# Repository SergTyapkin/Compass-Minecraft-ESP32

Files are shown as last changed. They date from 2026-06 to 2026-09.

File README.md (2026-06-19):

# 🧭 ESP32-C3 Compass & GPS Navigator

**Компас с дизайном из майнкрафта на LED-матрице с магнитометром, GPS-трекером и индикацией заряда аккумулятора**

---

## 📖 Оглавление
1. [Описание проекта](#-описание-проекта)
2. [Функционал](#-функционал)
3. [Управление](#-управление)
4. [Компоненты](#-компоненты)
5. [Схема подключения](#-схема-подключения)
6. [Установка и запуск (PlatformIO)](#-установка-и-запуск-platformio-для-новичков)
7. [Конфигурация](#-конфигурация)
8. [Структура проекта](#-структура-проекта)

---

## 🎯 Описание проекта

Этот проект представляет собой портативный навигационный прибор на базе ESP32-C3 SuperMini с LED-матрицей 8×8. Устройство сочетает в себе:

- **Электронный компас** на основе магнитометра QMC5883L
- **GPS-навигатор** с отображением направления и расстояния до заданной точки
- **Индикатор заряда аккумулятора** с визуальной анимацией на матрице
- **Управление режимами** одной кнопкой

Идеально подходит для геокешинга и подобных квестов или просто как интересный DIY-проект.

---

## ⚡ Функционал

| Режим | Описание |
|---|---|
| **🧭 Компас** | Показывает направление на магнитный север. Стрелка на матрице указывает текущий азимут. Красная стрелка компаса |
| **🎯 GPS-направление** | При наличии GPS-фикса показывает направление (азимут) к сохранённой точке. Зеленая стрелка компаса |
| **📏 GPS-расстояние** | Отображает расстояние до сохранённой точки (в метрах) с цветовой индикацией. Если расстояние > 100 м, количество зеленых кваратиков - количество десятков метров. Если квадратиков матрицы не хватает и метров больше (7x7 * 10), каждый оранжевый квадратик означает 100 м. Если не хватает и оранжевых, то каждый красный означает 1км. |
| **🔋 Индикатор зарядки** | Автоматический режим при подключении зарядки: анимация заполнения батарейки. Зеленая батарейка при полной зарядке. Красная мигающая при проблемах с аккумулятором |

### Дополнительные возможности:
- **Регулировка яркости** LED-матрицы (удержание кнопки)
- **Сохранение GPS-точки** (тройной клик в GPS-режимах)
- **Калибровка компаса** (тройной клик в режиме компаса. Зеленая полоска при калибровке - процент сканирования пространства. Синяя - время калибровки)
- **Автосохранение настроек** в файловой системе LittleFS
- **Визуальная обратная связь** на LED-матрице

---

## 🎮 Управление

Управление осуществляется одной тактильной кнопкой:

| Действие | Результат |
|---|---|
| **Удержание** | Регулировка яркости |
| **1 клик** | Переключение в режиме `GPS`: `GPS-направление` ↔ `GPS-расстояние` |
| **2 клика** | Переключение режима: `Компас` ↔ `GPS` |
| **3 клика** | В режиме `Компас` — **калибровка компаса**<br>В режиме `GPS` — **сохранение текущей позиции** |

> 💡 **Режим зарядки** активируется автоматически при подключении USB-питания. Кнопка в этом режиме неактивна.

---

## 🧩 Компоненты

### 📟 Основные модули

| Компонент | Модель | Ссылка |
|---|---|---|
| Микроконтроллер | ESP32-C3 SuperMini | [Купить на AliExpress](https://ali.click/mwv2d15) |
| GPS-модуль | GY-NEO6MV2 | [Купить на AliExpress](https://ali.click/pvv2d1n) |
| Магнитометр | GY-271 QMC5883L | [Купить на AliExpress](https://ali.click/bvv2d1o) |

### 🔘 Управление и мелочёвка
Нам нужна только одна кнопка и один переключатель
| Компонент | Описание | Ссылка |
|---|---|---|
| Тактильная кнопка | 6×6 мм для управления | [Купить на AliExpress](https://ali.click/jux2d1k) |
| Металлические кнопки | 4×4 мм (для корпуса) | [Купить на AliExpress](https://ali.click/rux2d1s) |
| Переключатели | Мини-переключатели TLZWLA | [Купить на AliExpress](https://ali.click/kyx2d1n) |
| Кулисный переключатель | KCD11-101 | [Купить на AliExpress](https://ali.click/yey2d12) |
| Закладные гайки | M2, M2.5, M3 медные | [Купить на AliExpress](https://ali.click/si03d1q) |

### 💡 Светодиоды

| Компонент | Описание | Ссылка |
|---|---|---|
| LED-матрица | WS2812B 8×8 (Если вы, как и я, не хотите паять матрицу сами. В проекте использована она) | [Купить на AliExpress](https://ali.click/kqo5d1t) |
| WS2812B 2020 | Мини-светодиоды 1.8×2 мм (если хотите паять маленькую матрицу сами) | [Купить на AliExpress](https://ali.click/hzw2d1a) |
| WS2812B 2×2 мм | Компактные RGB-чипы (если хотите паять маленькую матрицу сами) | [Купить на AliExpress](https://ali.click/8ow2d1k) |

### 🔋 Питание

| Компонент | Описание | Ссылка |
|---|---|---|
| Аккумулятор | Любой 3.7V. Я взял 14500, 800 мАч. Можно взять плоский, и сделать корпус тоньше | ссылки нет |
| Плата зарядки | TP4056 Type-C | [Купить на AliExpress](https://ali.click/huv2d18) |

---

## 🔌 Схема подключения

### Основные соединения

| ESP32-C3 | Подключение к |
|---|---|
| **GPIO5** | Кнопка (GND при нажатии) |
| **GPIO0** | LED-матрица (DATA) |
| **GPIO8 (SDA)** | QMC5883L (SDA) |
| **GPIO9 (SCL)** | QMC5883L (SCL) |
| **GPIO20 (RX)** | GPS (TX) |
| **GPIO21 (TX)** | GPS (RX) — опционально |
| **GPIO1** | Датчик заряда (CHG) — LOW при зарядке. Берется с катода красного светодиода индикации зарядки с платы зарядки TP4056. Подключается через подтяжку через резистор 5-10кОм к 3.3V от платы ESP32  |
| **GPIO2** | Датчик заряда (FULL) — LOW при полной зарядке. Берется с катода синего светодиода индикации полного заряда с платы зарядки TP4056. Подключается через подтяжку через резистор 5-10кОм к 3.3V от платы ESP32 |

### Питание

Идеальная схема такая:
```
Внешний блок 5V 2A+
├── 5V  ├──► LED-матрица VCC
|       └──► ESP32-C3 5V
|
└── GND ├──► LED-матрица GND
        └──► ESP32-C3 GND
```

Но у нас:
```
Аккумулятор 3.7V 1A
├── 5V  ├──► LED-матрица VCC
|       └──► ESP32-C3 5V
|
└── GND ├──► LED-матрица GND
        └──► ESP32-C3 GND
```

> ⚠️ **Важно!** LED-матрица требует отдельного питания (не через ESP32). Ведите провод на матрицу сразу от аккумулятора. Общий GND обязателен для всех компонентов.

---

## 🚀 Установка и запуск (PlatformIO для новичков)

### 1. Установка PlatformIO

**Вариант A: Расширение для VS Code (рекомендуется)**

1. Скачайте и установите [Visual Studio Code](https://code.visualstudio.com/)
2. Откройте VS Code, перейдите во вкладку **Extensions** (Ctrl+Shift+X)
3. Найдите **PlatformIO IDE** и установите
4. Перезапустите VS Code

**Вариант B: Альтернативная IDE (CLion, Qt Creator)**

Для других IDE мы подготовили специальный файл `.idea` для быстрого запуска в CLion, а также расширение для Qt Creator. Вы можете использовать любой удобный редактор при наличии установленного PlatformIO Core.

### 2. Клонирование проекта

```bash
git clone https://github.com/SergTyapkin/Compass-Minecraft-ESP32.git
cd Compass-Minecraft-ESP3
```

**Если у вас нет Git:**
- Скачайте ZIP-архив проекта и распакуйте в папку

### 3. Открытие проекта

- В VS Code: **File → Open Folder...** → выберите папку проекта
- PlatformIO автоматически распознает проект

### 4. Подключение платы

1. Подключите ESP32-C3 к компьютеру через USB-C кабель
2. Убедитесь, что в системе появился COM-порт:
   - **Windows:** Диспетчер устройств → Порты (COM и LPT)
   - **Linux:** `ls /dev/ttyUSB*` или `ls /dev/ttyACM*`
   - **macOS:** `ls /dev/cu.usb*`

### 5. Сборка и загрузка прошивки

**Способ 1: Через интерфейс VS Code**
1. Нажмите на иконку PlatformIO в левой панели (в виде пиктограммы с головой робота)
2. В разделе **PROJECT TASKS** выберите:
   - **Build** — сборка проекта
   - **Upload** — загрузка прошивки на плату
   - **Upload and Monitor** — загрузка и открытие монитора порта

**Способ 2: Через терминал**
```bash
pio run --target upload --environment esp32-c3-super-mini
```

### 6. Мониторинг порта

Для просмотра отладочных сообщений:

```bash
pio device monitor --baud 115200
```

Или VS Code кнопка: **Upload and Monitor** сделает это автоматически.

### 7. Первый запуск

После успешной загрузки:
1. На LED-матрице должны загореться тестовые огни
2. В мониторе порта появится сообщение `✅ SETUP COMPLETE!`
3. Начните использовать устройство согласно инструкции управления

---

## ⚙️ Конфигурация

Все настройки проекта находятся в файле [config.h](firmware/src/config.h)

### Индивидуальная настройка

- **Магнитное склонение:** `mag.head.declinDeg = 10` (для вашего региона)
- **Остальные пины и переменные** в config.h

---

## 📁 Структура проекта

```
esp32-compass/
├── src/
│   ├── main.cpp          # Основной код
│   ├── config.h          # Конфигурация пинов
│   ├── icons.h           # Спрайты (иконки на матрице)
│   ├── matrix.h          # Работа с LED-матрицей
│   ├── gfx.h             # Графические примитивы
│   ├── arrows.h          # Данные стрелки компаса
│   ├── arrows.cpp        # Логика стрелки компаса
│   ├── battery.h         # Класс мониторинга заряда
│   └── numbers.h         # Шрифты (цифры 0-9)
├── platformio.ini        # Конфигурация PlatformIO
└── README.md             # Этот файл
```

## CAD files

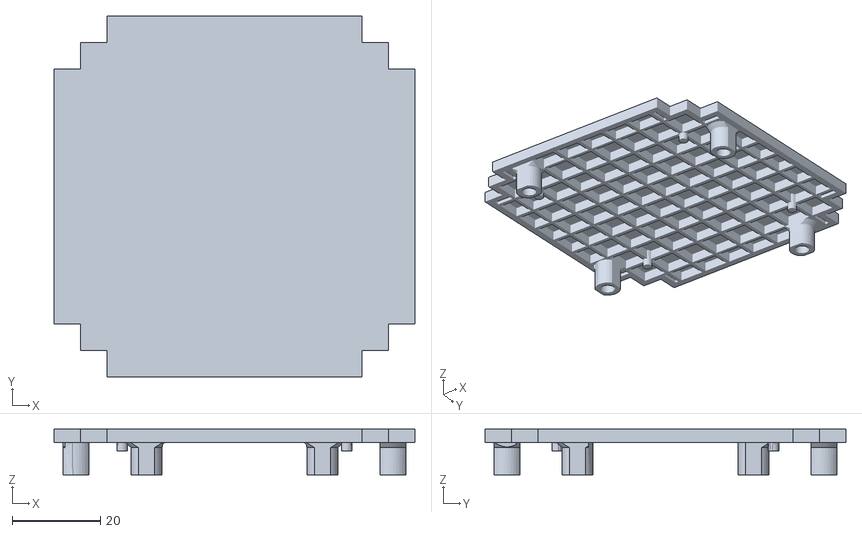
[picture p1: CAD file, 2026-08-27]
3D-модели (STL на печать)/Корпус крышка.stl
82.0 x 82.0 x 10.4

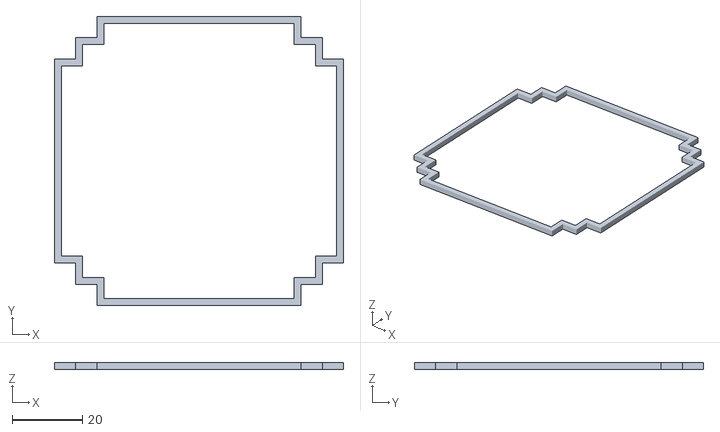
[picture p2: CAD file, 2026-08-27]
3D-модели (STL на печать)/Корпус окантовка.stl
82.0 x 82.0 x 2.00

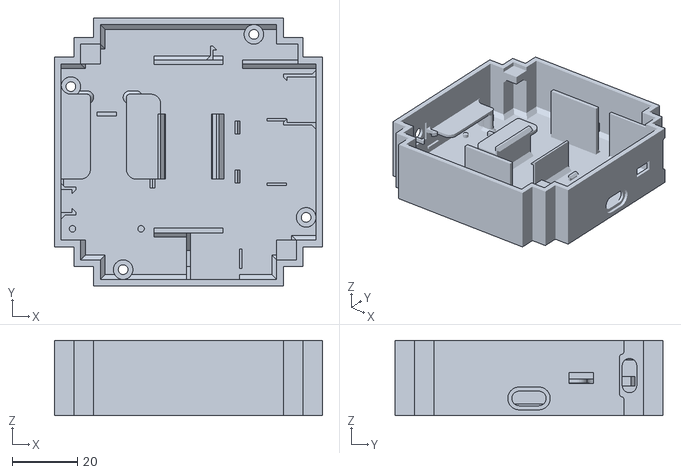
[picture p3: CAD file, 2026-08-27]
3D-модели (STL на печать)/Корпус основа.stl
82.0 x 82.0 x 23.0

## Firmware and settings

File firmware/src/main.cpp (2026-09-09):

#include <Arduino.h>
#include <FileData.h>
#include <GTimer.h>
#include <LittleFS.h>
#include <QMC5883L.h>
#include <TinyGPSPlus.h>
#include <Wire.h>
#include <uButton.h>

#include "config.h"
#include "icons.h"
#include "matrix.h"
#include "battery.h"
#include "timeManager.h"
#include "medianFilter.h"

/*
    Управление кнопкой:

    Удержание:
        В любом режиме - именение яркости. При отпускании и зажатии заново меняет направление изменения яркости (вниз / вверх)
    1x клик:
        🧭 в режиме компаса - ничего
        🌐 в режиме GPS - переключение - показать расстояние до точки / направление к ней
        🕓 в реижме часов - переключение - показать время стрелкой компаса / самими часами
    2x клик - смена режима по кругу:
        => 🧭 Режим компаса -> 🌐 Режим GPS -> 🕓 Режим часов =>
    3x клик:
        🧭 в режиме компаса - калибровка компаса
        🌐 в режиме GPS - запомнить точку
        🕓 в реижме часов - синхрнизация с NPT сервером
*/

enum class Mode {
    Charging,
    Compass,
    TargetDir,
    TargetDist,
    Clock,
    ClockCompass,
};

struct Data {
    uint8_t brightness = 30;
    Mode mode = Mode::Compass;
    MagCal cal;
    float lat;
    float lng;
};
Data cfg;
FileData fdata(&LittleFS, "/cfg.cfg", 'A', &cfg, sizeof(cfg));

uButton btn(BTN_PIN);

QMC5883L mag(I2C_MAG_ADDR);
MedianFilter<int16_t, MAG_FILTER_SIZE> magFilterX;
MedianFilter<int16_t, MAG_FILTER_SIZE> magFilterY;
MedianFilter<int16_t, MAG_FILTER_SIZE> magFilterZ;

TinyGPSPlus gps;

Battery battery(BATTERY_CHARGING_PIN, BATTERY_FULL_PIN);

TimeManager timeManager(WIFI_SSID_NAME, WIFI_PASSWORD, NTP_SERVER_HOST, GMT_OFFSET_SEC, DAYLIGHT_OFFSET_SEC, true);

// Цвета для вывода обычного компаса (красная стрелка)
static uint32_t DefaultCompassArrowColors[] = {
    Adafruit_NeoPixel::Color(255, 0, 0),     // Яркая стрелка
    Adafruit_NeoPixel::Color(60, 0, 0),      // Темная стрелка
    Adafruit_NeoPixel::Color(120, 120, 120), // Центр
};

// Цвета для вывода направления в GPS режиме (зеленая стрелка)
static uint32_t GPSCompassArrowColors[] = {
    Adafruit_NeoPixel::Color(0, 255, 0),     // Яркая стрелка
    Adafruit_NeoPixel::Color(0, 60, 0),      // Темная стрелка
    Adafruit_NeoPixel::Color(120, 120, 120), // Центр
};

// Цвета для вывода часов (красная стрелка)
static uint32_t HourClockCompassArrowColors[] = {
    Adafruit_NeoPixel::Color(255, 0, 0),     // Яркая стрелка
    Adafruit_NeoPixel::Color(60, 0, 0),      // Темная стрелка
    Adafruit_NeoPixel::Color(0, 0, 0), // Центр делаем прозрачным
};
// Цвета для вывода минут (синяя стрелка)
static uint32_t MinuteClockCompassArrowColors[] = {
    Adafruit_NeoPixel::Color(0, 0, 255),     // Яркая стрелка
    Adafruit_NeoPixel::Color(0, 0, 60),      // Темная стрелка
    Adafruit_NeoPixel::Color(0, 0, 0),       // Центр делаем прозрачным
};
// Цвета для вывода дисплея часов
static uint32_t ClockColors[] = {
    Adafruit_NeoPixel::Color(0, 0, 180),     // Светлое небо
    Adafruit_NeoPixel::Color(0, 0, 60),      // Темное небо
    Adafruit_NeoPixel::Color(255, 255, 0),   // Светлая часть стрелки солнца
    Adafruit_NeoPixel::Color(60, 60, 0),     // Темная часть стрелки солнца
    Adafruit_NeoPixel::Color(255, 255, 255), // Светлая часть стрелки луны
    Adafruit_NeoPixel::Color(60, 60, 60),    // Темная часть стрелки луны
};

// ===== BUZZER STATE =====
static bool victoryPointReached = false;
static unsigned long victoryStartTime = 0;
static int victoryNoteIndex = 0;
static bool victoryPlaying = false;

// ===== ANIMATIONS VARS =====
static unsigned long const INITIAL_TIME = millis();

bool onCalibrate(const MagCalProgress& progressMsg) {
    disp.clear();
    disp.color = 0xffff00; // yellow
    disp.drawRectStroke(0, PROGRESS_BAR_Y, PROGRESS_BAR_WIDTH, PROGRESS_BAR_HEGIHT);
    
    // Draw progress
    int progress = progressMsg.balance / CALIBRATION_MIN_PERCENT * (PROGRESS_BAR_WIDTH - 2);
    if (progress > (PROGRESS_BAR_WIDTH - 2)) progress = (PROGRESS_BAR_WIDTH - 2);       // 0.. 8
    disp.color = 0x00ff00; // green
    disp.drawRect(1, PROGRESS_BAR_Y + 1, progress, PROGRESS_BAR_HEGIHT - 3);

    // Draw time
    int elapsedProgress = float(progressMsg.elapsed) / CALIBRATION_MIN_TIME_MS * (PROGRESS_BAR_WIDTH - 2);
    if (elapsedProgress > (PROGRESS_BAR_WIDTH - 2)) elapsedProgress = (PROGRESS_BAR_WIDTH - 2);
    disp.color = 0x0000ff; // blue
    disp.drawRect(1, PROGRESS_BAR_Y + PROGRESS_BAR_HEGIHT - 2, elapsedProgress, 1);

    disp.update();

    return progressMsg.elapsed > CALIBRATION_MIN_TIME_MS && progressMsg.balance > CALIBRATION_MIN_PERCENT;
}

// ===== VICTORY MELODY =====
// Простая восходящая победная мелодия
void playVictoryMelody() {
    // Ноты: C5, D5, E5, G5, C6 (восходящая гамма)
    const int notes[] = {523, 587, 659, 784, 1047};
    const int noteCount = 5;
    
    for (int i = 0; i < noteCount; i++) {
        ledcSetup(BUZZER_PWM_CHANNEL, notes[i], BUZZER_PWM_RESOLUTION);
        ledcWrite(BUZZER_PWM_CHANNEL, 128);  // 50% duty cycle
        delay(BUZZER_TONE_DURATION);
        ledcWrite(BUZZER_PWM_CHANNEL, 0);
        delay(50);  // small pause between notes
    }
}

// ===== NON-BLOCKING VICTORY MELODY =====
void startVictoryMelody() {
    Serial.println("  🔊 Start playing winning melody!");
    victoryPlaying = true;
    victoryNoteIndex = 0;
    victoryStartTime = millis();
    victoryPointReached = true;  // чтобы не повторять
}

void tickBuzzer() {
    if (!victoryPlaying) return;
    
    // Ноты: C5, D5, E5, G5, C6
    const int notes[] = {523, 587, 659, 784, 1047};
    const int noteCount = 5;
    const int noteDuration = 150;
    const int pauseDuration = 50;
    
    static unsigned long lastNoteTime = 0;
    static bool playingNote = true;
    
    if (victoryNoteIndex >= noteCount) {
        // Мелодия завершена
        ledcWrite(BUZZER_PWM_CHANNEL, 0);
        victoryPlaying = false;
        Serial.println("  🔈 Winnng melody played to the end");
        return;
    }
    
    unsigned long now = millis();
    
    if (playingNote) {
        // Включаем ноту
        if (now - lastNoteTime >= noteDuration) {
            ledcWrite(BUZZER_PWM_CHANNEL, 0);
            playingNote = false;
            lastNoteTime = now;
        }
    } else {
        // Пауза между нотами
        if (now - lastNoteTime >= pauseDuration) {
            victoryNoteIndex++;
            if (victoryNoteIndex < noteCount) {
                ledcSetup(BUZZER_PWM_CHANNEL, notes[victoryNoteIndex], BUZZER_PWM_RESOLUTION);
                ledcWrite(BUZZER_PWM_CHANNEL, 128);
                playingNote = true;
                lastNoteTime = now;
            } else {
                // Мелодия завершена
                victoryPlaying = false;
            }
        }
    }
}

void setup() {
    Serial.begin(115200);
    Serial.println("\n╔═══════════════════════════════════╗");
    Serial.println("║     ESP32-C3 GPS Compass          ║");
    Serial.println("╚═══════════════════════════════════╝\n");
    
    Serial.println("STEP 0: Initializing Battery Monitor...");
    battery.init();
    Serial.println("  ✅ Battery monitor initialized");

    Serial.println("STEP 1: Initializing GPS...");
    Serial0.begin(9600, SERIAL_8N1, GPS_UART_PIN_RX, GPS_UART_PIN_TX);  // RX, TX
    Serial.printf("  ✅ GPS UART initialized on pins %d(RX), %d(TX)\n", GPS_UART_PIN_RX, GPS_UART_PIN_TX);

    Serial.println("STEP 2: Initializing File System...");
    LittleFS.begin(true);
    fdata.read();
    Serial.println("  ✅ LittleFS mounted");
    Serial.printf("  ✅ Config loaded: brightness=%d, mode=%d\n", cfg.brightness, (int)cfg.mode);

    Serial.println("STEP 3: Initializing LED Matrix...");
    strip.begin();
    strip.setBrightness(cfg.brightness);
    strip.clear();
    strip.show();
    Serial.println("  ✅ NeoPixel initialized");

    Serial.println("STEP 4: Initializing Magnetometer...");
    Wire.begin(I2C_SDA_PIN, I2C_SCL_PIN);
    Wire.setClock(100000);
    Serial.printf("  ✅ I2C initialized on pins %d(SDA), %d(SCL)\n", I2C_SDA_PIN, I2C_SCL_PIN);

    // Проверяем наличие датчика
    Serial.printf("  🔍 Scanning for magnetometer at 0x%x... ", I2C_MAG_ADDR);
    Wire.beginTransmission(I2C_MAG_ADDR);
    byte error = Wire.endTransmission();
    if (error == 0) {
        Serial.println("✅ FOUND!");
    } else {
        Serial.printf("❌ NOT FOUND! Error: %d\n", error);
        Serial.printf("  Check wiring: SDA=GPIO%d, SCL=GPIO%d, VCC=3.3V, GND=GND\n", I2C_SDA_PIN, I2C_SCL_PIN);
    }
    
    // Принудительная инициализация магнитометра
    Serial.print("  ⚙️  Configuring magnetometer registers... ");
    // 1. Сброс датчика (запись 0x01 в регистр 0x0B)
    Wire.beginTransmission(I2C_MAG_ADDR);
    Wire.write(0x0B);  // Register RESET
    Wire.write(0x01);  // Soft reset
    Wire.endTransmission();
    delay(10);
    // 2. Настройка Control Register (0x09)
    // Биты: [7:6] OSR (00=512 samples)
    //       [5:4] RNG (01=8G)
    //       [3:2] ODR (11=200Hz)
    //       [1:0] MODE (01=continuous mode)
    Wire.beginTransmission(I2C_MAG_ADDR);
    Wire.write(0x09);  // Control register
    Wire.write(0x1D);  // 0b00011101 = continuous mode, 200Hz, 8G, 512 samples
    Wire.endTransmission();
    delay(10);
    // 3. Настройка Set/Reset Period (0x0A)
    Wire.beginTransmission(I2C_MAG_ADDR);
    Wire.write(0x0A);  // Control2 register
    Wire.write(0x01);  // Enable set/reset
    Wire.endTransmission();
    delay(10);
    byte writeError = Wire.endTransmission();
    if (writeError == 0) {
        Serial.println("✅ Control register set to 0x1D");
    } else {
        Serial.printf("❌ Write failed! Error: %d\n", writeError);
    }
    delay(100);
    
    mag.begin();
    mag.cal = cfg.cal;
    Serial.println("  ✅ Magnetometer initialized");

    // ось y вперёд
    mag.head.axis[0] = 0;
    mag.head.axis[1] = 1;
    mag.head.sign[0] = 1;
    mag.head.sign[1] = 1;
    mag.head.declinDeg = 10;
    Serial.println("  ✅ Magnetometer axes configured");

    // сброс фильтров
    magFilterX.reset();
    magFilterY.reset();
    magFilterZ.reset();
    Serial.printf("  ✅ Median filters initialized (size: %d)\n", MAG_FILTER_SIZE);

    // ===== BUZZER INIT =====
    Serial.println("STEP 5: Initializing Buzzer...");
    ledcSetup(BUZZER_PWM_CHANNEL, 440, BUZZER_PWM_RESOLUTION);
    ledcAttachPin(BUZZER_PIN, BUZZER_PWM_CHANNEL);
    ledcWrite(BUZZER_PWM_CHANNEL, 0);
    Serial.printf("  ✅ Buzzer initialized on pin %d\n", BUZZER_PIN);

    // ===== TimeManager INIT =====
    Serial.println("STEP 6: Initializing TimeManager...");
    timeManager.begin();
    Serial.println("  ✅ TimeManager initialized succcessfully");

    // ----- Завершение инициализации
    Serial.println("\n═══════════════════════════════════════");
    Serial.println("✅ SETUP COMPLETED!");
    Serial.println("═══════════════════════════════════════\n");
    
    Serial.println("Controls:");
    Serial.println("  🔄 1 click:");
    Serial.println("    🧭 Compass - nothing");
    Serial.println("    🌐 GPS -     switch target/dist mode");
    Serial.println("    🕓 Clock -   switch compass/clock visual mode");
    Serial.println("  🔄 2 clicks:");
    Serial.println("     Switch mode > 🧭 Compass -> 🌐 GPS -> 🕓 Clock >");
    Serial.println("  🔄 3 clicks:");
    Serial.println("    🧭 Calibrate compass");
    Serial.println("    🌐 Save GPS point");
    Serial.println("    🕓 Sync clock using WiFi");
    Serial.println("  🔄 Hold - adjust brightness\n");
}

void loop() {
    btn.tick();
    fdata.tick();
    tickBuzzer();

    if (Serial0.available()) {
        gps.encode(Serial0.read());
    }

    // ------ Display
    EVERY16_MS(30) { // 30 ms for 30+ fps
        disp.clear();

        Serial.println("\n💠 System monitor info:");
        Serial.printf("  🔆 Brightness: %d / 255\n", cfg.brightness);
        // Проверка подключения зарядки
        Battery::State batteryState = battery.getState();
        Serial.printf(
            "  🔋 Battery state: %s\n", 
            batteryState == Battery::State::STATE_CHARGING ? "🟡 Charging" :
            batteryState == Battery::State::STATE_FULL ? "🟢 Full" :
            batteryState == Battery::State::STATE_ERROR ? "🔴 Error" :
            batteryState == Battery::State::STATE_NOT_CHARGING ? "🔻 OK" :
            "❓ Unknown"
        );

        // Проверка пинов на всякий случай
        const bool batteryIsChargerConnected = battery.isChargerConnected();
        bool chargingPinValue = digitalRead(BATTERY_CHARGING_PIN) == LOW;
        bool fullPinValue = digitalRead(BATTERY_FULL_PIN) == LOW;
        Serial.printf("  🔋 Battery charger connected: %s\n", batteryIsChargerConnected ? "🟢" : "🔸");
        Serial.printf("  🔋 Charging pin:              %s\n", chargingPinValue ? "🟢" : "🔸");
        Serial.printf("  🔋 Full pin:                  %s\n", fullPinValue ? "🟢" : "🔸");
        if (batteryIsChargerConnected) { // Если зарядка подключена - переключаем в режим зарядки
            cfg.mode = Mode::Charging;
            fdata.update();
        } else { // Если нет - возвращаем в обычный, но только если была зарядка
            if (cfg.mode == Mode::Charging) {
                cfg.mode = Mode::Compass;
                fdata.update();
            }
        }

        switch (cfg.mode) {
            case Mode::Charging: {
                Serial.println("💠 Mode: 🔋 Charging");
                switch (battery.getState()) { // Проверяем состояние батарейки
                    case Battery::STATE_FULL: {
                        // ===== РИСУЕМ БАТАРЕЙКУ С ПЛАВНЫМ ПЕРЕЛИВОМ =====
                        unsigned long timeFromStart = millis() - INITIAL_TIME;
                        
                        // Получаем оттенок цвета
                        uint16_t hue = 
                            ANIMATION_BATTERY_FULL_HUE_INITIAL_DEG * 256 +
                            sin(timeFromStart * ANIMATION_BATTERY_FULL_HUE_ANIMATION_SPEED) *
                            ANIMATION_BATTERY_FULL_HUE_AMPLITUDE_DEG * 256;
                        uint32_t frameColor = strip.ColorHSV(hue, 255, ANIMATION_BATTERY_FULL_HUE_BRIGHTNESS);
                        
                        // Рисуем батарейку с плавно меняющимся цветом
                        disp.color = frameColor;
                        disp.drawSprite(battery_full, sizeof(battery_full), 0, 1);
                        Serial.println(" 🔋 Battery FULL");
                        break;
                    }
                    
                    case Battery::STATE_CHARGING: {
                        // ===== 1. РИСУЕМ КОРПУС БАТАРЕЙКИ С ПЛАВНЫМ ПЕРЕЛИВОМ =====
                        unsigned long timeFromStart = millis() - INITIAL_TIME;
                        
                        // Получаем оттенок цвета
                        uint16_t hue = 
                            ANIMATION_BATTERY_HUE_INITIAL_DEG * 256 +
                            sin(timeFromStart * ANIMATION_BATTERY_HUE_ANIMATION_SPEED) *
                            ANIMATION_BATTERY_HUE_AMPLITUDE_DEG * 256;
                        uint32_t frameColor = strip.ColorHSV(hue, 255, ANIMATION_BATTERY_HUE_BRIGHTNESS);
                        
                        // Рисуем корпус батарейки с плавно меняющимся цветом
                        disp.color = frameColor;
                        disp.drawSprite(battery_frame, sizeof(battery_frame), 0, 1);
                        
                        // ===== 2. АНИМАЦИЯ ЗАПОЛНЕНИЯ ПОЛОСЫ ЗАРЯДКИ ГРАДИЕНТНОЙ ВОЛНОЙ =====
                        static unsigned long lastAnimUpdate = 0;
                        static int wavePosition = -ANIMATION_WAVE_WIDTH;
                        
                        // Обновляем анимацию (волна шагает)
                        if (millis() - lastAnimUpdate > ANIMATION_WAVE_STEP_MS) {
                            lastAnimUpdate = millis();
                            
                            // Фаза волны
                            wavePosition++;
                            if (wavePosition > ANIMATION_WAVE_MAX_POSITION) {
                                wavePosition = -ANIMATION_WAVE_WIDTH;
                            }
                        }
                        
                        // Определяем яркость каждого пикселя в зависимости от позиции волны
                        // Используем 5x2 область полосы для заполнения (x = 1..5, y = 2..3)
                        for (int y = 2; y <= 3; y++) {
                            for (int x = 1; x <= 5; x++) {
                                // Вычисляем расстояние от текущей позиции до центра волны
                                int distFromWave = abs(x - wavePosition);
                                
                                // Яркость зависит от расстояния до центра волны:
                                uint8_t brightness = 0;
                                // Ремаппинг расстояния в яркость (0-max) -> (255-0)
                                brightness = map(distFromWave, 0, ANIMATION_WAVE_WIDTH + 0.01, ANIMATION_WAVE_MAX_BRIGHTNESS, 0);
                                
                                if (distFromWave > ANIMATION_WAVE_WIDTH) {
                                    continue;
                                }

                                uint32_t waveColor = strip.ColorHSV(ANIMATION_WAVE_HUE_DEG * 256, 255, brightness);
                                disp.color = waveColor;
                                disp.drawPixel(x, y);
                            }
                        }
                        break;
                        Serial.println(" 🔋 Battery in charging... Playing wave animation");
                    }
                    
                    case Battery::STATE_ERROR: {
                        // Ошибка - быстро моргаем красной батарейкой
                        static bool blinkState = false;
                        static unsigned long lastBlink = 0;
                        
                        if (millis() - lastBlink > 200) {
                            lastBlink = millis();
                            blinkState = !blinkState;
                        }
                        
                        if (blinkState) {
                            disp.color = 0xff0000;
                            disp.drawSprite(battery_frame, sizeof(battery_frame), 0, 1);
                            Serial.println(" 🔋❌ BATTERY ERROR!");
                        } else {
                            disp.clear();
                        }
                        break;
                    }
                    
                    case Battery::STATE_NOT_CHARGING: // Вообще мы не долдны сюда попадать, но на всякий случай
                    default: {
                        // Не заряжается - тусклая рамка батарейки
                        disp.color = 0x444444;
                        disp.drawSprite(battery_frame, sizeof(battery_frame), 0, 1);
                        Serial.println(" 🔋 Not charging");
                        break;
                    }
                }
                break;
            }

            case Mode::Compass: {
                // ===== ЧТЕНИЕ С ФИЛЬТРАЦИЕЙ =====
                MagRaw rawValues = mag.readRaw();
                
                // Добавляем в фильтры
                magFilterX.add(rawValues.x);
                magFilterY.add(rawValues.y);
                magFilterZ.add(rawValues.z);
                
                // Получаем отфильтрованные значения
                int16_t filteredX, filteredY, filteredZ;
                if (magFilterX.isFull()) {
                    filteredX = magFilterX.getMedian();
                    filteredY = magFilterY.getMedian();
                    filteredZ = magFilterZ.getMedian();
                } else {
                    // Пока фильтр не заполнен, используем сырые данные
                    filteredX = rawValues.x;
                    filteredY = rawValues.y;
                    filteredZ = rawValues.z;
                }
                
                // Вычисляем heading из отфильтрованных данных
                float heading = atan2(filteredY, filteredX);
                if (heading < 0) heading += TWO_PI;
                
                Serial.println("💠 Mode: 🧭 Compass");
                Serial.printf("  🧭 RAW values: X=%6d Y=%6d Z=%6d\n", rawValues.x, rawValues.y, rawValues.z);
                Serial.printf("  🧭 FILT values: X=%6d Y=%6d Z=%6d\n", filteredX, filteredY, filteredZ);
                Serial.printf("  🧭 Heading=%.2f rad (%.1f°)\n", heading, degrees(heading));
                
                // Выводим стрелку компаса
                showArrowRad(COMPASS_ROTATION_OFFSET_RAD - heading, DefaultCompassArrowColors);
                break;
            }

            case Mode::TargetDir:
                Serial.println("💠 Mode: 🌐 GPS target to DIR");

                if (gps.location.isValid()) {
                    Serial.printf("  🌐 GPS: Lat=%.6f Lon=%.6f Sats=%d\n", gps.location.lat(), gps.location.lng(), gps.satellites.value());
                    float headDeg = gps.courseTo(gps.location.lat(), gps.location.lng(), cfg.lat, cfg.lng);
                    float heading = mag.headingRad();
                    Serial.printf("  🌐 TargetDir: headDeg=%.2f, heading=%.2f\n", headDeg, heading);
                    showArrowRad(radians(headDeg) - heading, GPSCompassArrowColors);
                    float hdop = gps.hdop.hdop();
                    disp.color = Adafruit_NeoPixel::ColorHSV(hdop ? map(hdop, 20, 0, 0, 20000) : 0);
                    disp.drawPixel(5, 2);  // center
                } else {
                    Serial.printf("  🌐 GPS: ❌ No fix (satellites=%d)\n", gps.satellites.value());
                    disp.color = 0xff0000;
                    disp.drawSprite(cross, sizeof(cross));
                }
                break;

            case Mode::TargetDist:
                Serial.println("💠 Mode: 🌐 GPS DIST to target");
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

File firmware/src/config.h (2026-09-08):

#pragma once

// Button
#define BTN_PIN 5                         // Пин кнопки

// LED matrix
#define LED_PIN 0                        // Пин для сигнала в LED-матрицу
#define LED_COUNT 64                     // Количество светодиодов (8×8)
#define LED_MATRIX_WIDTH 8               // Ширина матрицы (отдельно, потому что она может быть сложной формы. Это размеры описанного прямоугольника вокруг неё)
#define LED_MATRIX_HEIGHT 8              // Высота матрицы

// Pins I2C (Magnitometer)
#define I2C_SDA_PIN 8                    // SDA для магнитометра
#define I2C_SCL_PIN 9                    // SCL для магнитометра
#define I2C_MAG_ADDR 0x2C                // I2C адрес QMC5883L (обычно 0x0D)

// GPS pins and distance
#define GPS_UART_PIN_RX 20               // RX ESP32 (подключается к TX GPS)
#define GPS_UART_PIN_TX 21               // TX ESP32 (подключается к RX GPS)
#define GPS_DISTANCE_TO_POINT_REACHED_METERS 3 // Расстояние до точки, чтобы она считалась достигнутой

// Buzzer
#define BUZZER_PIN 4                     // Пин пьезоэлемента (пищалки)
#define BUZZER_PWM_CHANNEL 1             // Ну надо так
#define BUZZER_PWM_RESOLUTION 8          // Ну надо так
#define BUZZER_TONE_DURATION 150         // ms на одну ноту музыки

// Pins Battery Monitor (TP4056 plate)
#define BATTERY_CHARGING_PIN 2           // Пин индикации зарядки с TP4056 (LOW = заряжается)
#define BATTERY_FULL_PIN 1               // Пин индикации заряда с TP4056 (LOW = заряжена)

// Calibration parameters
#define CALIBRATION_MIN_TIME_MS 10000
#define CALIBRATION_MIN_PERCENT 0.75

// Filtering
#define MAG_FILTER_SIZE 15               // Размер медианного фильтра для магнитометра

// Time manager settings
#define WIFI_SSID_NAME "Sergs-Archer-E204"    // Название сети Wifi
#define WIFI_PASSWORD "<YOUR_WIFI_PASSWORD>"  // Пароль от Wifi
#define NTP_SERVER_HOST "pool.ntp.org"   // Хост NTP сервера для синхронизации времени
#define GMT_OFFSET_SEC (3 * 60 * 60)     // Смещение часового пояса GMT+3
#define DAYLIGHT_OFFSET_SEC 0            // Смещение летнего/зимнего времени

// Controls
#define BRIGHTNESS_STEP 5                // Шаг яркости при зажатии кнопки
#define BRIGHTNESS_MIN  1                // Минимальное значение яркости
#define BRIGHTNESS_MAX  255              // Максимальное значение яркости

// Visuals
#define COMPASS_ROTATION_OFFSET_RAD (PI)    // Смещение при выводе фреймов компаса (чтобы направление севера магнитометра совпадало со стрелкой)
// 🔁 Calibration progressbar params
#define PROGRESS_BAR_HEGIHT 4                                         // Ширина прогрессбара (по вертикали. Не меньше 4)
#define PROGRESS_BAR_WIDTH LED_MATRIX_WIDTH                           // Длина прогрессбара (по вертикали. Не меньше 5)
#define PROGRESS_BAR_Y ((LED_MATRIX_HEIGHT - PROGRESS_BAR_HEGIHT) / 2)  // Y позиция, откуда рисуем прогрессбар
// 🔋🟡 Charging animantion params
// | Corpus
#define ANIMATION_BATTERY_HUE_INITIAL_DEG 32                 // Средний оттенок в HSV для заряжающейся батарейки (30 - желтый)
#define ANIMATION_BATTERY_HUE_AMPLITUDE_DEG 10               // Амплитуда анимации оттенка для заряжающейся батарейки
#define ANIMATION_BATTERY_HUE_ANIMATION_SPEED 0.001          // Скорость изменения оттенка для заряжающейся батарейки
#define ANIMATION_BATTERY_HUE_BRIGHTNESS cfg.brightness      // Яркость анимации заряжающейся батарейки
// | Filling
#define ANIMATION_WAVE_WIDTH 5                               // Длина изредка пробегающей волны зарядки
#define ANIMATION_WAVE_MAX_POSITION 15                       // Дальнее положение пробегающей волны зарядки
#define ANIMATION_WAVE_STEP_MS 30                            // Скорость пробегания волны
#define ANIMATION_WAVE_MAX_BRIGHTNESS cfg.brightness         // Яркость волны
#define ANIMATION_WAVE_HUE_DEG 50                            // Оттенок в HSV для волны (50 - между желтым и зеленым)
// 🔋🟢 Charged animantion params
#define ANIMATION_BATTERY_FULL_HUE_INITIAL_DEG 90            // Средний оттенок в HSV для заряженной батарейки (90 - зеленый)
#define ANIMATION_BATTERY_FULL_HUE_AMPLITUDE_DEG 15          // Амплитуда анимации оттенка для заряженной батарейки
#define ANIMATION_BATTERY_FULL_HUE_ANIMATION_SPEED 0.001     // Скорость изменения оттенка для заряженной батарейки
#define ANIMATION_BATTERY_FULL_HUE_BRIGHTNESS cfg.brightness // Яркость анимации заряженной батарейки
// 🕓 Clock
#define CLOCK_MATRIX_X 0       // Начало отрисовки часов на матрице по X
#define CLOCK_MATRIX_Y 0       // Начало отрисовки часов на матрице по Y
#define CLOCK_MATRIX_WIDTH 7   // Ширина области матрицы для часов. Лучше нечетные числа
#define CLOCK_MATRIX_HEIGHT 7  // Высота области матрицы для часов. Лучше нечетные числа
// 🌐 GPS
#define GPS_MATRIX_X 0       // Начало отрисовки gps компаса на матрице по X
#define GPS_MATRIX_Y 0       // Начало отрисовки gps компаса на матрице по Y
#define GPS_MATRIX_WIDTH 7   // Ширина области матрицы для gps компаса
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

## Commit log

2026-06-19 Удалил лишние файлы, обновил код, добавил кучу плюшек, написал ридми
    [minecompass.3mf]
2026-06-23 Добавил проигрывание мелодии при достижени целевой точки в режиме GPS
2026-06-24 Сделал красивые градиентные анимации зарядки и уже заряженной батарейки
2026-08-10 Сделал дополнительный режим - часы. Пока что не сделал вид часов как в майнкрафте
2026-08-11 Добавил дисплей для часов с 28 фреймами часов из майнкрафта
2026-08-20 Починил часовую стрелку и удалил лишнюю переменную
2026-08-24 Поправил вычисление времени
2026-08-27 Добавил 3D-модели
    [Корпус крышка.stl, Корпус окантовка.stl, Корпус основа.stl]
2026-09-09 Fix daylight time offset
    [main.cpp]
